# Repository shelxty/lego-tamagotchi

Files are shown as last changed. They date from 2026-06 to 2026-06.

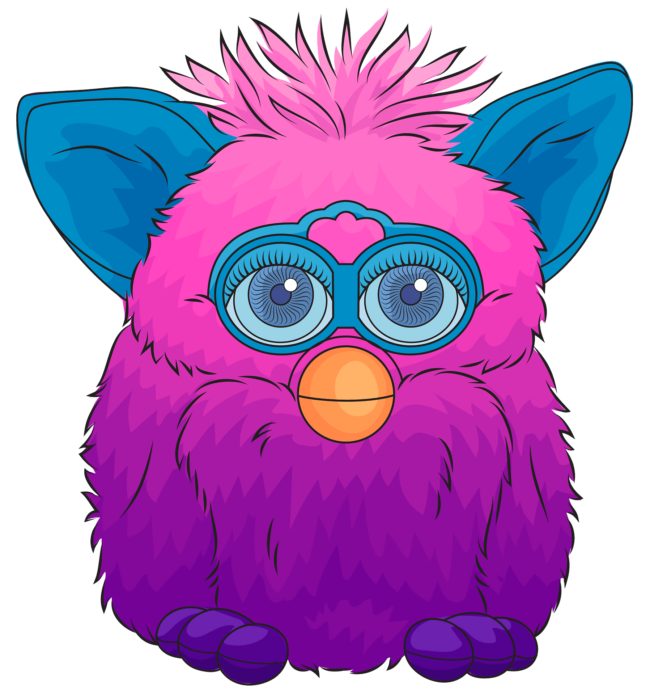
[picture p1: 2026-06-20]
design/furby-pngmart.png

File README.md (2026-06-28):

# Lego Tamagotchi!

This is a tamagotchi (a virtual pet) modeled after a lego piece! Created for Hack Club's #Fallout YSWS. It's my first larger-scale hardware project! 

AssemblyLego2

_He says hello! And also asks you to help him find a name! (Because I'm not creative)_

## Motivation 
As a complete beginner in hardware, I was absolutely lost on what hardware was. I had looked at a few KiCad tutorials, but each time I was confused -- what the hell was ground? What's the difference between 5V and 3.3V? Why are some things wired like that? But on a trip back from NYC with Tanishq, he gave me a good explanation on what hardware was, and how to get started with it. I was surprised to hear that he made his very own full-fleshed tutorial for those beginning in hardware, and honestly, I'll credit Tanishq and this tutorial for truly teaching me what hardware is. I'm still a beginner, but at least I've made that first step from zero to... one! Yay! 

Anyways, this is my first completed hardware project that uses both PCBs and CAD. Thank you Tanishq! 

## How It Works / How It's Used

### Components: 

| **Designator** | **Part** | **Wiring** | **Purpose** |
|---|---|---|---|
| U1 | Seeed Studio XIAO ESP32-C3 | N/A | Made by Seeed Studio, it's a miniature ESP32 that uses a USB-C for power; it's a microcontroller capable of WiFi and Bluetooth. Everything else on the PCB gives this module inputs, outputs, and power | 
| BT1 | Single-cell battery | N/A | This powers the whole board, connected to the XIAO BATT+ charging input pins | 
| SW1 , SW2, SW3 | 3 push buttons | GPIO2 (D0), GPIO3 (D1), and GPIO4 (D2), respectively | These push buttons allow the user to interact with the tamagotchi | 
| U2 | 0.96 inch OLED display (SSD1315) | SDA is wired to GPIO6 (D4) and SCL is wired to GPIO7 (D5), while VCC takes in 3.3V | This is the display for the pet -- it's the area that allows you to actually play and interact with your tamagotchi | 
| BUZZER1 | A piezoelectric buzzer | GPIO10 (D10) (MOSI) | This is the sound output. Whenever you press an action, the tamagotchi responds by buzzing with the buzzer to provide feedback. |

### Hardware: 

- **Tool:** KiCad 10
- **Board:** 2-layer PCB with a custom outline
- **Microcontroller:** The Seeed Studio XIAO ESP32-C3
- **Display:** A 0.96" 128x64 OLED display with a SSD1315 driver
- **Audio:** A piezoelectric buzzer approximately 12 millimeters in diameter
- **Input:** 3 push buttons embedded onto the PCB 

---

Lego Tamagotchi Shelley Zine Fallout

_My zine!_

---
## PCB Design



_View of the schematic_



_View of the PCB (if you notice the little design in the middle, you should dm me on slack @shelx with a Matt Rose furby picture)_



_3D view_ 

...furbies...

anyways! 

---
## CAD 

This tamagotchi project got me to finally start learning how to CAD so wow! 

|  |  | 
|---|---|
| Exploded View | Frontal View | 
|  |  | 
| Back View | Side (Right) View |

The PCB is screwed in after the 3D printing is finished. 

Link to Onshape document: https://cad.onshape.com/documents/e4a64d821d7c72313f05382f/w/889a245c2565bee9629b9436/e/a5b00448e143d248d84f17b3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

To try it out, use the Wokwi simulator: https://wokwi.com/projects/467841668828380161

### Measurements (for 3D printing)

This should be able to be printed with a Bambu A1 mini! 
**Context:** A Bambu A1 mini bed size is 180mm x 180mm x 180mm.

- Leg: 120mm (height) x 64mm (length)
- Torso: 131mm (height) x 137mm (longest base) 
- Head: 43mm (height), 91mm (diameter)

---

## Bill of Materials (BOM) 

| Item |	Description |	Reference |	Qty |	MOQ |	Value |	Per Unit Price ($) |	Total Price ($) |	Footprint |	MPN |	URL |
|---|---|---|-----|-----|---|---|---|---|-----|-----|
| Battery |	Single-cell battery |	BT1 |	1 |	1 |	Battery_Cell |	3.87 |	3.87 |	Connector_PinHeader_2.54mm:PinHeader_1x02_P2.54mm_Vertical |	N/A |	[Link](https://www.aliexpress.us/item/3256808925172396.html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) |
| Buzzer |	Audio buzzer |	BUZZER1 |	1 |	10 |	1207-P6.5MM |	0.0572 |	0.57 |	easyeda2kicad:BUZ-TH_BD12.5-P6.50-D1.4 |	1207-P6.5MM |	[Link](https://www.lcsc.com/product-detail/C49246964.html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) |
| Buttons |	Push button switch, generic, two pins |	SW1,SW2,SW3 |	3 |	10 |	SW_Push |	0.053 |	0.53 |	easyeda2kicad:SW-TH_4P-L4.5-W4.5-P3.00-LS4.8 |	TS-1088-AR02016 |	[Link](https://www.lcsc.com/product-detail/C720477.html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) |
| MCU |	XIAO-ESP32-C3 |	U1 |	1 |	1 |	XIAO-ESP32-C3-SMD |	2.95 |	2.95 |	Seeed_Studio_XIAO_Series:XIAO-ESP32-C3-SMD |	N/A |	[Link](https://www.aliexpress.us/item/3256808694624250.html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) |
| OLED Display |	Display screen |	U2 |	1 |	1 |	HS96L03W2C03 |	2.24 |	2.24 |	easyeda2kicad:OLED-TH_L27.8-W27.2-P2.54_C9900033791 |	HS96L03W2C03 |	[Link](https://www.lcsc.com/product-detail/C5248080.html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)
| PCB Build |	JLCPCB |	N/A |	1 |	1 |	N/A |	2 |	2 |	N/A |	N/A |	N/A |
| PCB Shipping |	JLCPCB |	N/A |	1 |	1 |	N/A |	2.5 |	2.5 |	N/A |	N/A |	N/A |
| Total |		| |	9 |	25	|	|	| 14.66			

Credits: 
- For the tutorial: [@TaniWanKenobi's](https://github.com/TaniWanKenobi) tamagotchi guide [linked here](https://fallout.hackclub.com/docs/guided-projects/tamagotchi) (it's amazing!)
- A screw import: https://grabcad.com/library/screw-06-1
- Hack Club Fallout mentors!

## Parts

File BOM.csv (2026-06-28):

Item | Description | Reference | Qty | MOQ | Value | Per Unit Price ($) | Total Price ($) | Footprint | MPN | URL
Battery | Single-cell battery | BT1 | 1 | 1 | Battery_Cell | 3.87 | 3.87 | Connector_PinHeader_2.54mm:PinHeader_1x02_P2.54mm_Vertical | N/A | https://www.aliexpress.us/item/3256808925172396.html?curPageLogUid=gVBhZCgn1w6G
Buzzer | Audio buzzer | BUZZER1 | 1 | 10 | 1207-P6.5MM | 0.0572 | 0.57 | easyeda2kicad:BUZ-TH_BD12.5-P6.50-D1.4 | 1207-P6.5MM | https://www.lcsc.com/product-detail/C49246964.html?s_z=s_p_1207-P6.5MM
Buttons | Push button switch, generic, two pins | SW1,SW2,SW3 | 3 | 10 | SW_Push | 0.053 | 0.53 | easyeda2kicad:SW-TH_4P-L4.5-W4.5-P3.00-LS4.8 | TS-1088-AR02016 | https://www.lcsc.com/product-detail/C720477.html?s_z=s_q_p_PUSH%2520BUTTON%2520SWITCH
MCU | XIAO-ESP32-C3 | U1 | 1 | 1 | XIAO-ESP32-C3-SMD | 2.95 | 2.95 | Seeed_Studio_XIAO_Series:XIAO-ESP32-C3-SMD | N/A | https://www.aliexpress.us/item/3256808694624250.html?curPageLogUid=46Mmlu4FUmrg
OLED Display | Display screen | U2 | 1 | 1 | HS96L03W2C03 | 2.24 | 2.24 | easyeda2kicad:OLED-TH_L27.8-W27.2-P2.54_C9900033791 | HS96L03W2C03 | https://www.lcsc.com/product-detail/C5248080.html?s_z=n_q_HS96L03W2C03
PCB Build | JLCPCB | N/A | 1 | 1 | N/A | 2 | 2 | N/A | N/A | N/A
PCB Shipping | JLCPCB | N/A | 1 | 1 | N/A | 2.5 | 2.5 | N/A | N/A | N/A
Total |  |  | 9 | 25 |  |  | 14.66

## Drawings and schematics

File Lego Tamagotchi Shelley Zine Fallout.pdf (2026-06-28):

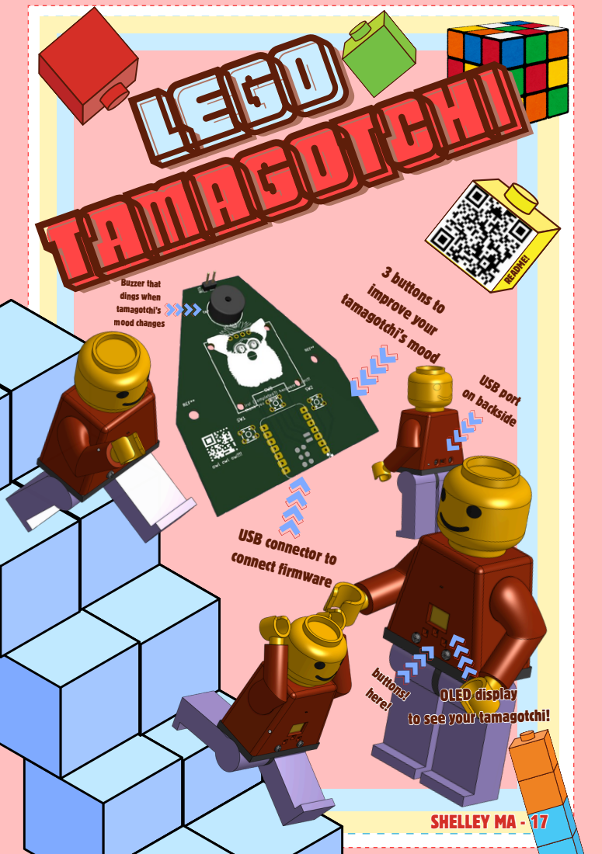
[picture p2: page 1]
LEGO TAMAGOTCHI; TAMAGOTCHI; LEGO TAMAGOTCHI TAMAGOTCHI; 3 buttons to improve your tamagotchi’s mood; B connector to ect firmware; Buzzer that dings when tamagotchi’s mood changes; OOLLEEDD ddiissppllaayy; OLED display; README!; USB port on backside; buttons! buttons! here!; buttons! here!; SSHHEELLLLEEYY MMAA -- 1177

to see your tamagotchi!

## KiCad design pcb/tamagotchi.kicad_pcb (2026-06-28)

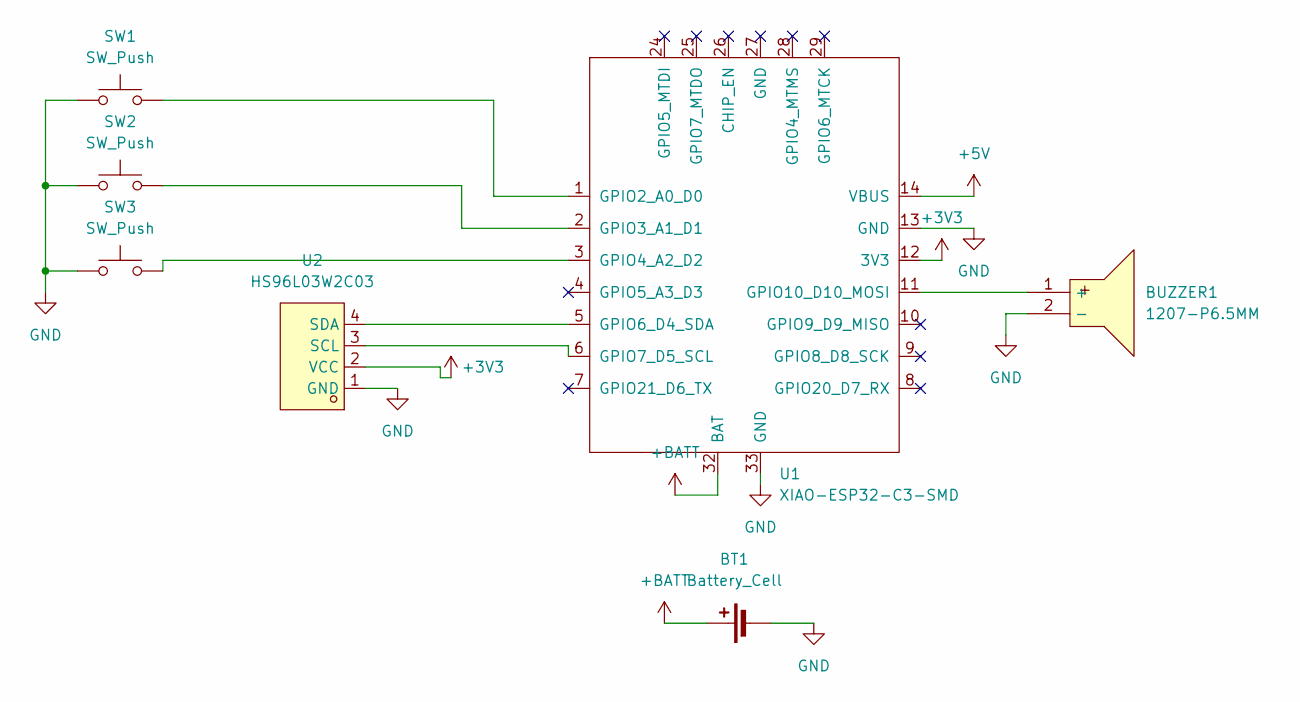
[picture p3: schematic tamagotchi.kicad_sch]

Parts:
BT1: Battery_Cell; PinHeader_1x02_P2.54mm_Vertical
BUZZER1: 1207-P6.5MM; BUZ-TH_BD12.5-P6.50-D1.4; MPN 1207-P6.5MM; LCSC Part C49246964
SW1, SW2, SW3: SW_Push; SW-TH_4P-L4.5-W4.5-P3.00-LS4.8
U1: XIAO-ESP32-C3-SMD
U2: HS96L03W2C03; OLED-TH_L27.8-W27.2-P2.54_C9900033791; MPN HS96L03W2C03; LCSC Part C5248080

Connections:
+3V3: U1.12 (3V3), U2.2 (VCC)
+5V: U1.14 (VBUS)
+BATT: BT1.1 (+), U1.32 (BAT)
GND: BT1.2 (-), BUZZER1.2 (-), SW1.1, SW2.1, SW3.1, U1.13 (GND), U1.33 (GND), U2.1 (GND)
unnamed: BUZZER1.1 (+), U1.11 (GPIO10_D10_MOSI)
unnamed: SW1.2, U1.1 (GPIO2_A0_D0)
unnamed: SW2.2, U1.2 (GPIO3_A1_D1)
unnamed: SW3.2, U1.3 (GPIO4_A2_D2)
unnamed: U1.5 (GPIO6_D4_SDA), U2.4 (SDA)
unnamed: U1.6 (GPIO7_D5_SCL), U2.3 (SCL)

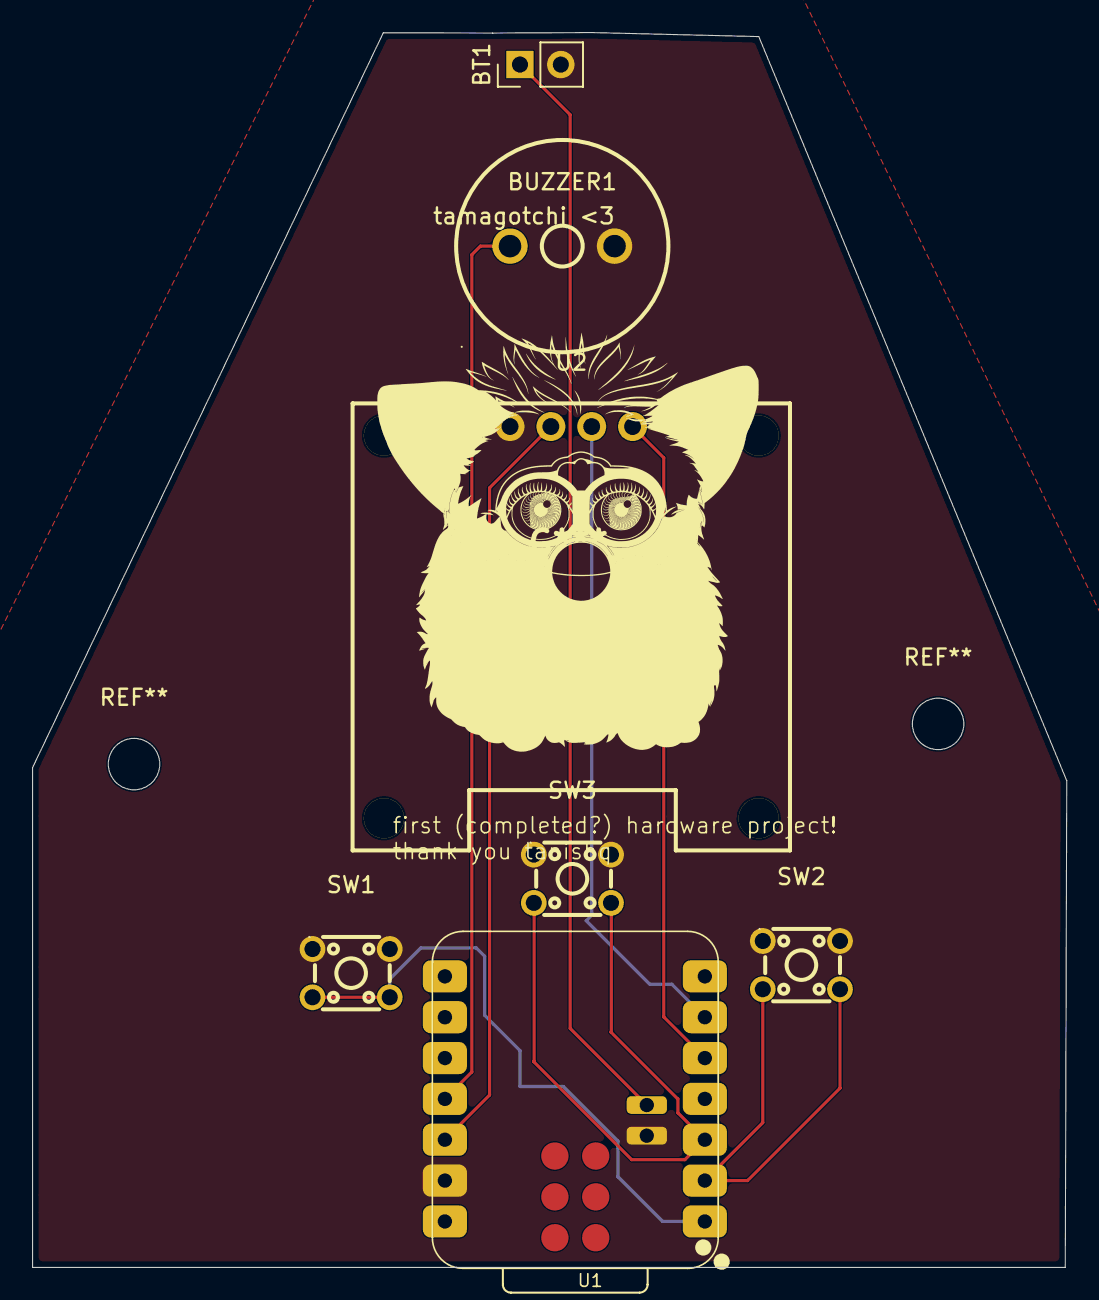
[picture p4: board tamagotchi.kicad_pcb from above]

Board: 2 copper layers, 64.3 x 76.8 mm, 7 parts (0 on the bottom side), 9 nets.

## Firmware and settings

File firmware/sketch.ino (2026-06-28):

// some of the previous buttons from the tutorial are gone because they served no purpose 

// I2C OLED (traced from schematic)
#define SDA_PIN D4  // OLED SDA → MCU Pin D4 → GPIO6
#define SCL_PIN D5  // OLED SCL → MCU Pin D5 → GPIO7

// Buzzer (traced from schematic)
// #define BUZZER D10   // Buzzer signal → MCU Pin 10 → GPIO10
  
#include <Wire.h>
#include <Adafruit_GFX.h>
#include <Adafruit_SSD1306.h> // installing the required libaries 

#define SCREEN_WIDTH 128
#define SCREEN_HEIGHT 64
#define OLED_RESET -1

Adafruit_SSD1306 display(SCREEN_WIDTH, SCREEN_HEIGHT, &Wire, OLED_RESET);

#define BTN_LEFT   D0 // rewiring some of the buttons as these are the ones traced from my schematic 
#define BTN_MIDDLE D1
#define BTN_RIGHT  D2
#define BUZZER_PIN D10


struct Pet {
  int hunger;       // 0 to 100 (0 = starving, while 100 = full)
  int happiness;    // 0 to 100 (0 = miserable, while 100 = ecstatic)
  int energy;       // 0 to 100 (0 = exhausted, while 100 = fully rested)
  unsigned long age; // total seconds the pet has been alive
};

Pet pet;

enum Screen {
  SCREEN_MAIN,
  SCREEN_FEED,
  SCREEN_PLAY,
  SCREEN_SLEEP
};

Screen currentScreen = SCREEN_MAIN;

void setup() {
  pinMode(BTN_LEFT, INPUT_PULLUP);
  pinMode(BTN_MIDDLE, INPUT_PULLUP);
  pinMode(BTN_RIGHT, INPUT_PULLUP);
  pinMode(BUZZER_PIN, OUTPUT);

  display.begin(SSD1306_SWITCHCAPVCC, 0x3C);
  display.clearDisplay();
  display.setTextSize(1);
  display.setTextColor(SSD1306_WHITE);
  display.setCursor(0, 0);
  display.println("Tamagotchi Init...");
  display.display();
  delay(1000);

  pet.hunger = 80; // set default values of 80, 80, 80, and 0 for hunger/happiness/energy/age respectiely 
  pet.happiness = 80;
  pet.energy = 80;
  pet.age = 0;
};

unsigned long lastUpdate = 0;

void updatePet() {
  if (millis() - lastUpdate > 5000) {  // every 5 seconds
    pet.hunger--;
    pet.happiness--;
    pet.energy--;

    if (pet.hunger < 0) pet.hunger = 0;
    if (pet.happiness < 0) pet.happiness = 0;
    if (pet.energy < 0) pet.energy = 0;

    pet.age += 5;
    lastUpdate = millis();
  }
}

unsigned long lastButtonPress = 0;
bool buttonWasPressed = false; 

void checkButtons() {
  if (millis() - lastButtonPress < 200) return;  // debounce: ignore presses within 200ms

  if (digitalRead(BTN_LEFT) == LOW) { // pull-up resistors working their thing
    currentScreen = SCREEN_FEED;
    tone(BUZZER_PIN, 1000, 50);
    lastButtonPress = millis();
    buttonWasPressed = true; 
  }
  else if (digitalRead(BTN_MIDDLE) == LOW) {
    currentScreen = SCREEN_PLAY;
    tone(BUZZER_PIN, 1200, 50);
    lastButtonPress = millis();
    buttonWasPressed = true; 
  }
  else if (digitalRead(BTN_RIGHT) == LOW) {
    currentScreen = SCREEN_SLEEP;
    tone(BUZZER_PIN, 800, 50);
    lastButtonPress = millis();
    buttonWasPressed = true; 
  }
}

void handleScreenLogic() {
  switch(currentScreen) {

    case SCREEN_FEED:
      pet.hunger += 10;
      if (pet.hunger > 100) pet.hunger = 100;
      currentScreen = SCREEN_MAIN;
      break;

    case SCREEN_PLAY:
      pet.happiness += 10;
      pet.energy -= 5;
      if (pet.happiness > 100) pet.happiness = 100;
      if (pet.energy < 0) pet.energy = 0;
      currentScreen = SCREEN_MAIN;
      break;

    case SCREEN_SLEEP:
      pet.energy += 15;
      if (pet.energy > 100) pet.energy = 100;
      currentScreen = SCREEN_MAIN;
      break;

    case SCREEN_MAIN:
      break;  // do nothing, just display stats
  }
}

// happy face is displayed if all results are above 50 
const unsigned char PROGMEM petHappy[] = {
  0b00000000, 0b00000000,
  0b00011111, 0b11111000,
  0b00100000, 0b00000100,
  0b01000000, 0b00000010,
  0b01001100, 0b00110010,
  0b01001100, 0b00110010,
  0b01000000, 0b00000010,
  0b01000000, 0b00000010,
  0b01000100, 0b00100010,
  0b01000011, 0b11000010,
  0b01000000, 0b00000010,
  0b00100000, 0b00000100,
  0b00011111, 0b11111000,
  0b00000000, 0b00000000,
  0b00000000, 0b00000000,
  0b00000000, 0b00000000
};

// sad face is displayed if any results < 30 
const unsigned char PROGMEM petSad[] = {
  0b00000000, 0b00000000,
  0b00011111, 0b11111000,
  0b00100000, 0b00000100,
  0b01000000, 0b00000010,
  0b01001100, 0b00110010,
  0b01001100, 0b00110010,
  0b01000000, 0b00000010,
  0b01000000, 0b00000010,
  0b01000000, 0b00000010,
  0b01000011, 0b11000010,
  0b01000100, 0b00100010,
  0b00100000, 0b00000100,
  0b00011111, 0b11111000,
  0b00000000, 0b00000000,
  0b00000000, 0b00000000,
  0b00000000, 0b00000000
};

// if no happy and no sad, then neutral yes
const unsigned char PROGMEM petNeutral[] = {
  0b00000000, 0b00000000,
  0b00011111, 0b11111000,
  0b00100000, 0b00000100,
  0b01000000, 0b00000010,
  0b01001100, 0b00110010,
  0b01001100, 0b00110010,
  0b01000000, 0b00000010,
  0b01000000, 0b00000010,
  0b01000111, 0b11100010,
  0b01000000, 0b00000010,
  0b01000000, 0b00000010,
  0b00100000, 0b00000100,
  0b00011111, 0b11111000,
  0b00000000, 0b00000000,
  0b00000000, 0b00000000,
  0b00000000, 0b00000000
};

// sleeping face (closed eyes)
const unsigned char PROGMEM petSleep[] = {
  0b00000000, 0b00000000,
  0b00011111, 0b11111000,
  0b00100000, 0b00000100,
  0b01000000, 0b00000010,
  0b01001111, 0b01110010,
  0b01000000, 0b00000010,
  0b01000000, 0b00000010,
  0b01000000, 0b00000010,
  0b01000011, 0b11000010,
  0b01000000, 0b00000010,
  0b01000000, 0b00000010,
  0b00100000, 0b00000100,
  0b00011111, 0b11111000,
  0b00000000, 0b00000000,
  0b00000000, 0b00000000,
  0b00000000, 0b00000000
};

void render() {
  display.clearDisplay();

  // this part actually chooses the sprite faces based on conditions
  const unsigned char* sprite;
  if (pet.hunger < 30 || pet.happiness < 30 || pet.energy < 30) {
    sprite = petSad;
  } else if (pet.hunger > 50 && pet.happiness > 50 && pet.energy > 50) {
    sprite = petHappy;
  } else {
    sprite = petNeutral;
  }

  display.drawBitmap(56, 2, sprite, 16, 16, SSD1306_WHITE); // draw sprite near the center at the top 

  display.setTextSize(1); // stat bars below the pet from left to right 

  display.setCursor(0, 24);
  display.print("HUN ");
  drawBar(24, 24, pet.hunger);

  display.setCursor(0, 34);
  display.print("HAP ");
  drawBar(24, 34, pet.happiness);

  display.setCursor(0, 44);
  display.print("ENG ");
  drawBar(24, 44, pet.energy);

  // Button labels at the bottom
  display.setCursor(0, 56);
  display.println("[Feed] [Play] [Sleep]");

  display.display();
}

void drawBar(int x, int y, int value) { // stat bar = empty rectangle with a filled portion based on value (0 to 100)
  int barWidth = 100;
  int barHeight = 6;
  int fillWidth = map(value, 0, 100, 0, barWidth);

  display.drawRect(x, y, barWidth, barHeight, SSD1306_WHITE);       // outline
  display.fillRect(x, y, fillWidth, barHeight, SSD1306_WHITE);      // filled portion
}

void loop() {
  buttonWasPressed = false; // loops over w/ these directions
  checkButtons();       // 1. Read input
  updatePet();          // 2. Update state over time
  if (buttonWasPressed) handleScreenLogic();  // 3. Process actions
  render();             // 4. Display results
  delay(100);           // 5. Short pause
}

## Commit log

2026-06-09 redid some routing and added a furby design because i keep thinking of matt rose furbies when i see tamagotchi
    [tamagotchi.kicad_pcb]
2026-06-20 version control for egg tamagotchi
    [tamagotchi-B_Cu.gbr, tamagotchi-B_Mask.gbr, tamagotchi-B_Paste.gbr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]
2026-06-20 finished routing and fixed DRC errors
    [tamagotchi.kicad_pcb]
2026-06-20 fixed up some really dumb xiao-esp32 issues (namely with the button numbers being wrong
    [tamagotchi.kicad_pcb]
2026-06-21 currently working on my readme
    adfasdf
2026-06-21 BOM
    bom bom bom!
    [tamagotchi.csv]
2026-06-21 renamed bom to bom
    [BOM.csv]
2026-06-21 Delete CAD/tamagotchi
    oops
2026-06-21 added some more stuff to readme for the pcb
2026-06-24 updated bom
    [BOM.csv]
2026-06-25 moved footprints and symbols over to the Library folder
    to make it all more organized
2026-06-28 edited pcb and added THT holes
    [tamagotchi.kicad_pcb]
2026-06-28 Add 3D printing measurements to README
    Added measurements for 3D printing specifications including leg, torso, and head dimensions.
